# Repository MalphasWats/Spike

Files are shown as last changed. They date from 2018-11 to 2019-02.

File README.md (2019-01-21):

# Spike

Spike is a handheld gaming console based on ATMega Microcontrollers.

Spike

I've been playing around with this idea for a long while and the Spike is the current 'state-of-the-art' for me.

The main spike board has:

* 128x64px monochrome OLED display
* Piezo speaker
* 7 buttons (plus reset)
* 3.7v Lipo battery
* Micro-USB port for charging & data

Spike Exploded

The *shard* board provides the brains and connects via an edge connector on the back of the main board.

Currently I'm using an ATMega1284p running at 16MHz.

I've written a little [more detail on my blog](http://www.subdimension.co.uk/2019/01/16/spike-next-gen-portable-gaming.html).

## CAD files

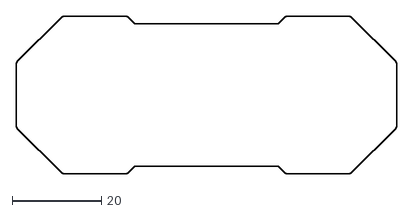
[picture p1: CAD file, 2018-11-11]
board_outline.dxf
85.3 x 35.3

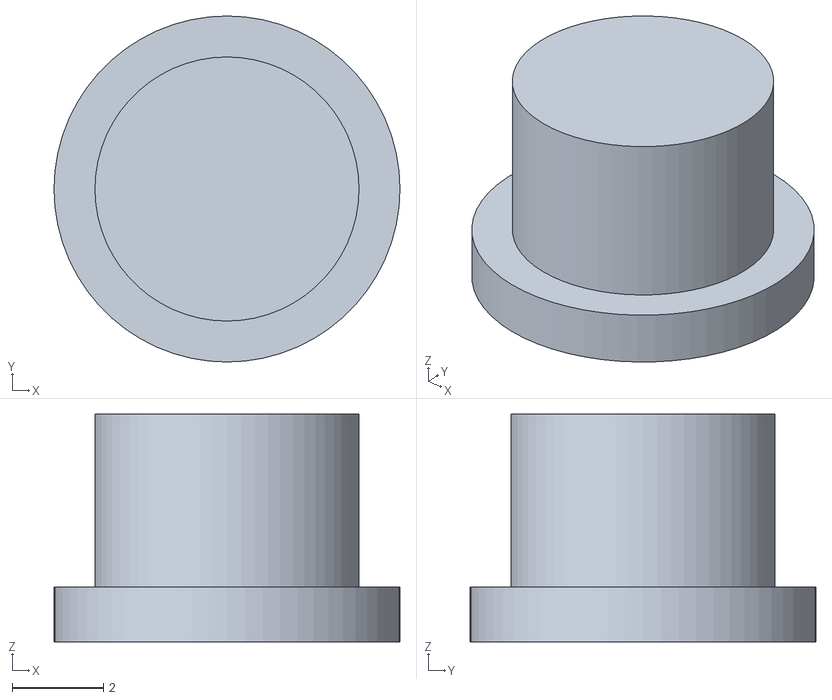
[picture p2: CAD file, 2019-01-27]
case/button-caps.stl
7.60 x 7.60 x 5.00

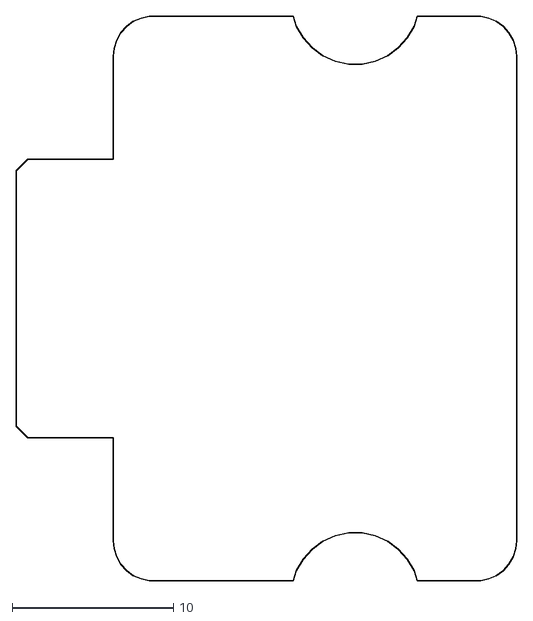
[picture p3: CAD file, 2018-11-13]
shard/outline.dxf
31.0 x 35.0

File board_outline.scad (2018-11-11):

module spike()
{
    minkowski()
    {
        union()
        {
            rotate([0, 0, 360/16]) circle(r=18, $fn=8);
            translate([50, 0, 0]) rotate([0, 0, 360/16]) circle(r=18, $fn=8);
            translate([25, 0]) square([32, 30], center=true);
        }
        circle(r=1, $fn=60);
    }
}

module shard()
{
    difference()
    {
        minkowski()
        {
            square([20, 30]);
            circle(r=2.5, $fn=30);
        }
        translate([12.5, -2.5-1]) circle(r=4, $fn=30);
        translate([12.5, 32.5+1]) circle(r=4, $fn=30);
    }
}

//color("red") translate([25, 0, 0.1]) square([28, 28], center=true);

spike();

//translate([40, -12, -2]) rotate([0, 0, 90]) color("blue") shard();

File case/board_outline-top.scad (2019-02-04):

module spike()
{
    minkowski()
    {
        union()
        {
            rotate([0, 0, 360/16]) circle(r=18, $fn=8);
            translate([50, 0, 0]) rotate([0, 0, 360/16]) circle(r=18, $fn=8);
            translate([25, 0]) square([32, 30], center=true);
        }
        circle(r=1, $fn=60);
    }
}

hole_size = 2 + 0.1;

difference()
{
    /*scale([1.02, 1.02])*/ translate([-25, 0]) spike();
    
    
    translate([-19, 15]) circle(d=hole_size, $fn=30);
    translate([19, 15]) circle(d=hole_size, $fn=30);
    
    translate([-31, -15]) circle(d=hole_size, $fn=30);
    translate([31, -15]) circle(d=hole_size, $fn=30);
    

    
        
    // Buttons
    
    translate([-25, 5]) rotate([0, 0, 45]) minkowski()
    {
        square([5, 5], center=true);
        circle(r=0.5, $fn=30);
    }
    
    translate([-25, -5]) rotate([0, 0, 45]) minkowski()
    {
        square([5, 5], center=true);
        circle(r=0.5, $fn=30);
    }
    
    translate([-30, 0]) rotate([0, 0, 45]) minkowski()
    {
        square([5, 5], center=true);
        circle(r=0.5, $fn=30);
    }
    translate([-20, 0]) rotate([0, 0, 45]) minkowski()
    {
        square([5, 5], center=true);
        circle(r=0.5, $fn=30);
    }
    
    // Case Mask
    /*translate([-25, 0]) rotate([0, 0, 45]) minkowski()
    {
        square([14, 14], center=true);
        circle(r=0.5, $fn=30);
    }*/
    
    
    translate([25, 5]) rotate([0, 0, 45]) minkowski()
    {
        square([5, 5], center=true);
        circle(r=0.5, $fn=30);
    }
    
    translate([25, -5]) rotate([0, 0, 45]) minkowski()
    {
        square([5, 5], center=true);
        circle(r=0.5, $fn=30);
    }
    
    translate([30, 0]) rotate([0, 0, 45]) minkowski()
    {
        square([5, 5], center=true);
        circle(r=0.5, $fn=30);
    }
    
    // Case Mask
    /*translate([25, 0]) rotate([0, 0, 45]) minkowski()
    {   
        difference()
        {
            square([14, 14], center=true);
            translate([-4, 4]) minkowski()
            {
                square([6, 6], center=true);
                circle(r=0.5, $fn=30);
            }
        }
        circle(r=0.5, $fn=30);
    }*/
    
    // usb
    translate([36, 11]) rotate([0, 0, -45]) minkowski()
    {
        square([6, 5], center=true);
        circle(r=0.5, $fn=30);
    }
    
}

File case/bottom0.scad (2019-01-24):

module spike()
{
    minkowski()
    {
        union()
        {
            rotate([0, 0, 360/16]) circle(r=18, $fn=8);
            translate([50, 0, 0]) rotate([0, 0, 360/16]) circle(r=18, $fn=8);
            translate([25, 0]) square([32, 30], center=true);
        }
        circle(r=1, $fn=60);
    }
}

hole_size = 2 + 0.1;

difference()
{
    scale([1.02, 1.02]) spike();
    
    
    translate([-15, 6.25]) circle(d=hole_size, $fn=30);
    translate([65.25, 6.25]) circle(d=hole_size, $fn=30);
    
    translate([-7.75, -13.25]) circle(d=hole_size, $fn=30);
    translate([57.75, -13.25]) circle(d=hole_size, $fn=30);
    
    
    // Battery Connector
    /*translate([52.00, 7]) hull()
    {
        circle(d=8, $fn=30);
        translate([-10.00, 0]) circle(d=8, $fn=30);
    }*/
    
    translate([50.00, 1]) minkowski()
    {
        square([15, 20], center=true);
        circle(d=1, $fn=30);
    }
    
    // Speaker
    translate([-7, 0]) circle(r=7, $fn=30);
    translate([-7, -7]) square([4, 4], center=true);
    
    // Shard socket
    translate([16, -17]) minkowski()
    {
        square([18, 10]);
        circle(r=0.8, $fn=30);
    }
    
    translate([16, 1]) minkowski()
    {
        square([18, 15]);
        circle(r=0.8, $fn=30);
    }
    
    /*translate([60, 12]) rotate([0, 0, 45]) minkowski()
    {
        square([4, 6], center=true);
        circle(r=0.5, $fn=30);
    }*/
    
    /*translate([40, -6]) rotate([0, 0, 90]) minkowski()
    {
        square([20, 30]);
        circle(r=2.5, $fn=30);
    }*/
}

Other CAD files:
case/base.scad
case/bottom1.scad
case/bottom2.scad
case/button-caps.scad
case/top0.scad
shard/outline.scad
shard_1284/outline.scad
shard_t84/outline.scad

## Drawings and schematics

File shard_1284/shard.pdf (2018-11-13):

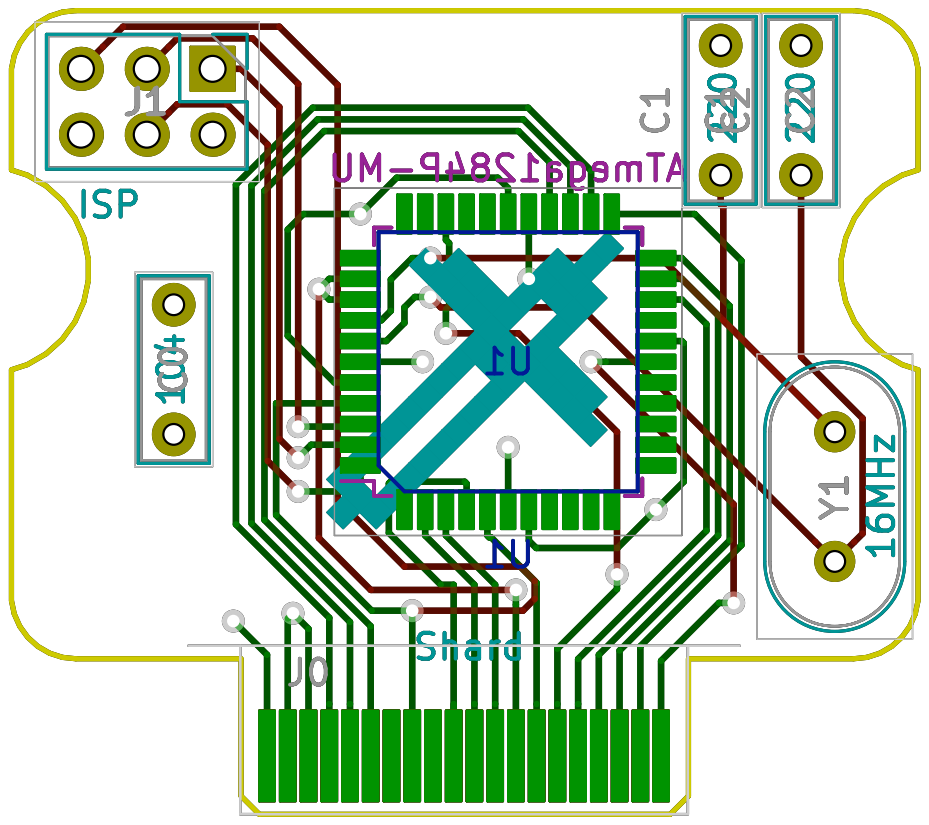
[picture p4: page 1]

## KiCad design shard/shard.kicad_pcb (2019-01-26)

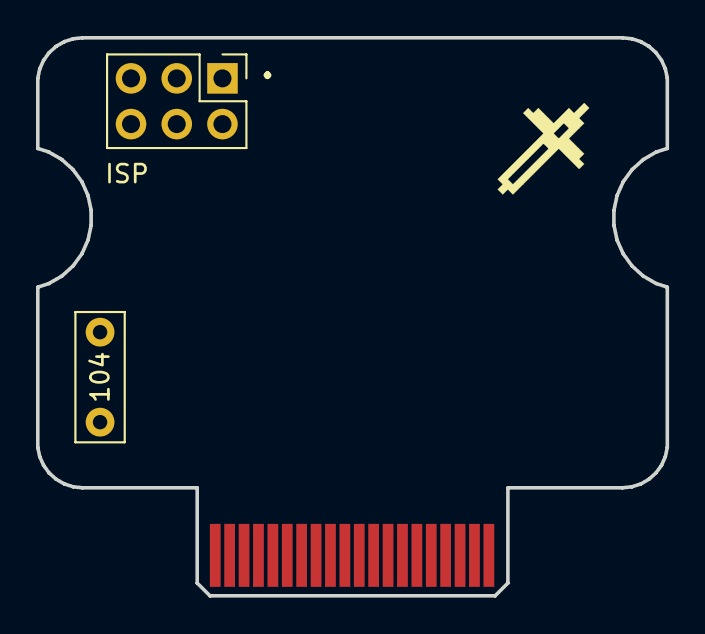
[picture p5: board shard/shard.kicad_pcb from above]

Board: 2 copper layers, 35.0 x 31.0 mm, 4 parts (0 on the bottom side), 3 nets, no tracks yet.

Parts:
C0: 104; C_Rect_L7.0mm_W2.5mm_P5.00mm
J0: Shard; Samtec_MEC8-120-02-L-D-RA1_Edge
J1: ISP; PinHeader_2x03_P2.54mm_Vertical
SPIKE: SPIKE

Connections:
+3V3: C0.1, J0.2, J1.2
GND: C0.2, J0.40, J1.6
RESET: J0.16, J1.5

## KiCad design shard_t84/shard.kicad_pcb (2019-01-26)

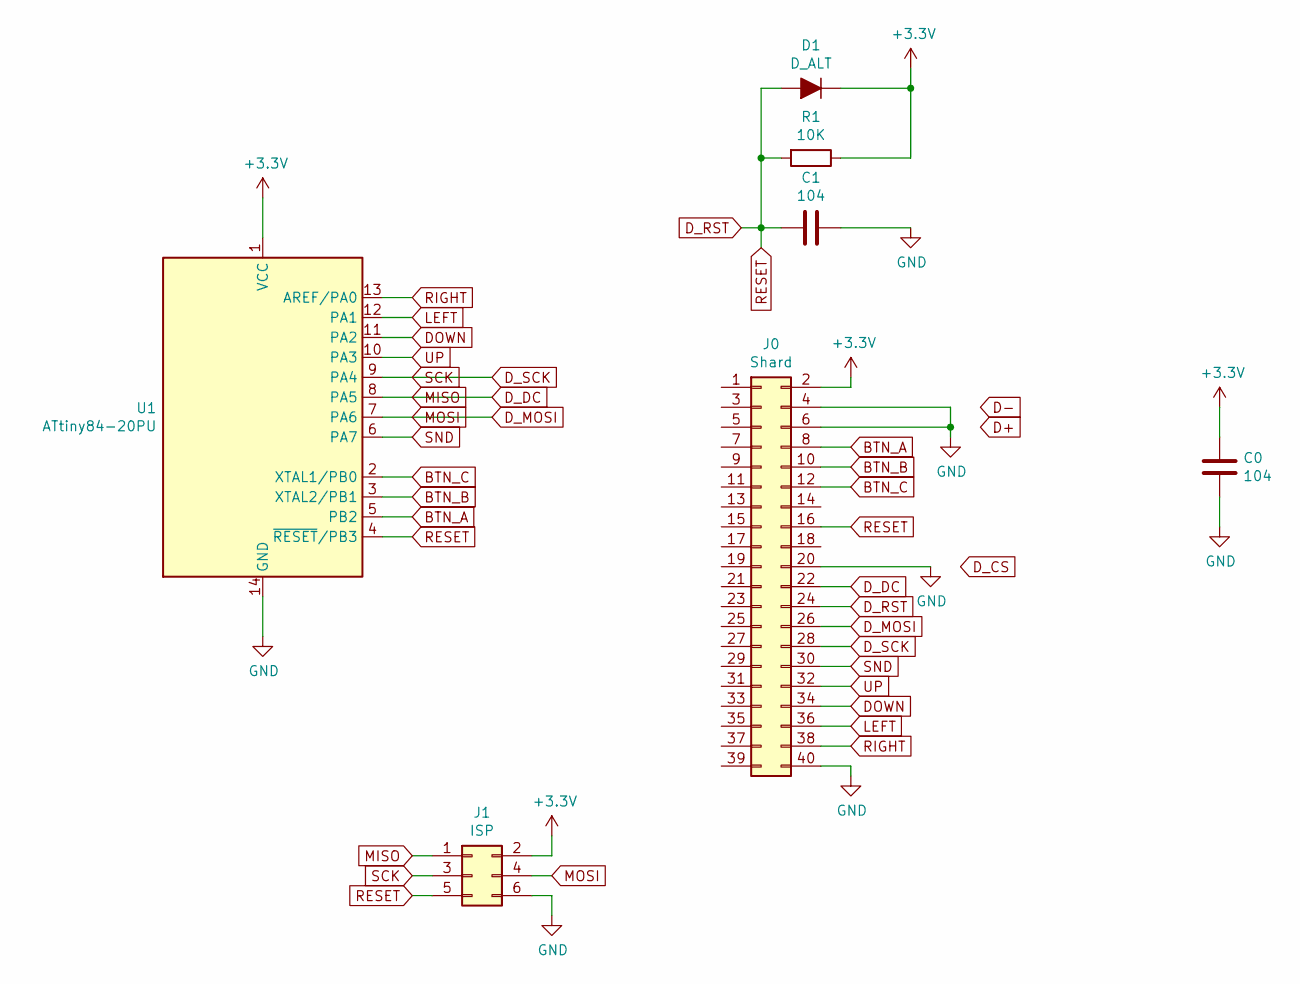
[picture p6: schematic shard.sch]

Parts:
C0, C1: 104; C_Rect_L7.0mm_W2.5mm_P5.00mm
D1: D_ALT; D_A-405_P7.62mm_Horizontal
J0: Shard; Samtec_MEC8-120-02-L-D-RA1_Edge
J1: ISP; PinHeader_2x03_P2.54mm_Vertical
R1: 10K; R_Axial_DIN0207_L6.3mm_D2.5mm_P7.62mm_Horizontal
U1: ATtiny84-20PU; DIP-14_W7.62mm

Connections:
+3V3: C0.1, D1.1 (K), J0.2, J1.2, R1.1, U1.1 (VCC)
BTN_A: J0.8, U1.5 (PB2)
BTN_B: J0.10, U1.3 (XTAL2/PB1)
BTN_C: J0.12, U1.2 (XTAL1/PB0)
DOWN: J0.34, U1.11 (PA2)
D_DC: J0.22, J1.1, U1.8 (PA5)
D_MOSI: J0.26, J1.4, U1.7 (PA6)
D_RST: C1.2, D1.2 (A), J0.16, J0.24, J1.5, R1.2, U1.4 (~RESET~/PB3)
D_SCK: J0.28, J1.3, U1.9 (PA4)
GND: C0.2, C1.1, J0.4, J0.6, J0.20, J0.40, J1.6, U1.14 (GND)
LEFT: J0.36, U1.12 (PA1)
RIGHT: J0.38, U1.13 (AREF/PA0)
SND: J0.30, U1.6 (PA7)
UP: J0.32, U1.10 (PA3)

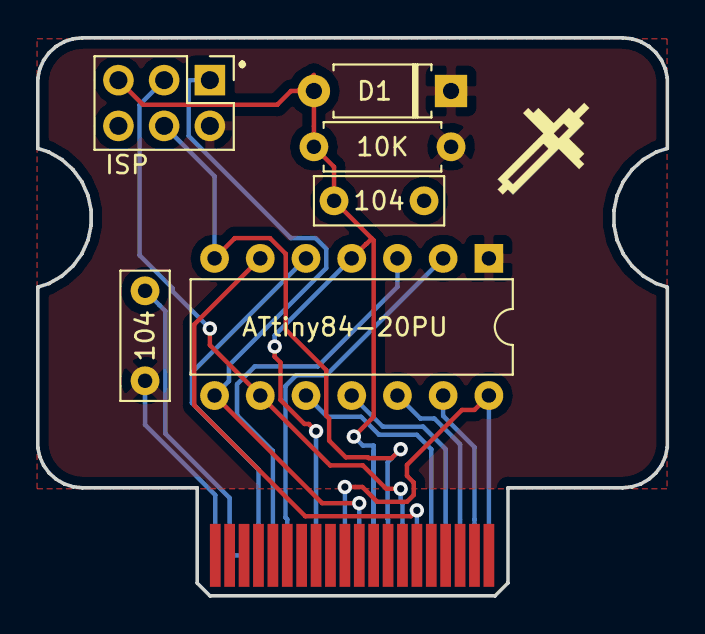
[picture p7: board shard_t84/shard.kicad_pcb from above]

Board: 2 copper layers, 35.0 x 31.0 mm, 8 parts (0 on the bottom side), 14 nets.

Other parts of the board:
SPIKE: SPIKE

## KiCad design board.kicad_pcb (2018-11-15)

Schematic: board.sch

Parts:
C1: 104; C_Rect_L7.0mm_W2.5mm_P5.00mm
C2, C3: 105; C_Rect_L7.0mm_W2.5mm_P5.00mm
C5, C6: 475; C_Rect_L7.0mm_W2.5mm_P5.00mm
D1: CHG; LED_D3.0mm
J0: Battery Pads; LiPo_Pads
J1: Shard; Samtec_MEC8-120-02-L-D-RA1_Socket
J2: USB-Micro; USB_Micro-B_Molex-105017-0001
LS1: Speaker; Generic_Speaker
R0: 1K; R_Axial_DIN0207_L6.3mm_D2.5mm_P7.62mm_Horizontal
R1: LED; R_Axial_DIN0207_L6.3mm_D2.5mm_P7.62mm_Horizontal
R2: 2K; R_Axial_DIN0207_L6.3mm_D2.5mm_P7.62mm_Horizontal
SW0: RESET; SW_PUSH_6mm
SW1: UP; SW_PUSH_6mm
SW2: DOWN; SW_PUSH_6mm
SW3: LEFT; SW_PUSH_6mm
SW4: RIGHT; SW_PUSH_6mm
SW5: BTN_A; SW_PUSH_6mm
SW6: BTN_B; SW_PUSH_6mm
SW7: BTN_C; SW_PUSH_6mm
SW8: POWER; SW_DIP_SPSTx01_Slide_9.78x4.72mm_W7.62mm_P2.54mm
U1: OLED; 128x64-OLED
U2: CHG CTRL; SOT-23-5
U3: Reg; SOT-23

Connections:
+3V3: C1.1, C3.1, J1.2, R0.1, U1.2, U3.2
+BATT: C6.1, J0.1, SW8.2, U2.3
BTN_A: J1.8, SW5.2
BTN_B: J1.10, SW6.2
BTN_C: J1.12, SW7.2
CHARGE: C5.1, D1.2, J2.1, U2.4
D+: J1.6, J2.3
D-: J1.4, J2.2
DOWN: J1.34, SW2.2
D_CS: J1.20, U1.7
D_DC: J1.22, U1.6
D_MOSI: J1.26, U1.4
D_RST: J1.24, U1.5
D_SCK: J1.28, U1.3
GND: C1.2, C2.2, C3.2, C5.2, C6.2, J0.2, J1.40, J2.4, J2.5, J2.6, LS1.1, R2.2, SW0.1, SW1.1, SW2.1, SW3.1, SW4.1, SW5.1, SW6.1, SW7.1, U1.1, U2.2, U3.1
LEFT: J1.36, SW3.2
unnamed: C2.1, SW8.1, U3.3
unnamed: D1.1, R1.2
unnamed: R1.1, U2.1
unnamed: R2.1, U2.5
RESET: J1.16, R0.2, SW0.2
RIGHT: J1.38, SW4.2
SND: J1.30, LS1.2
UP: J1.32, SW1.2

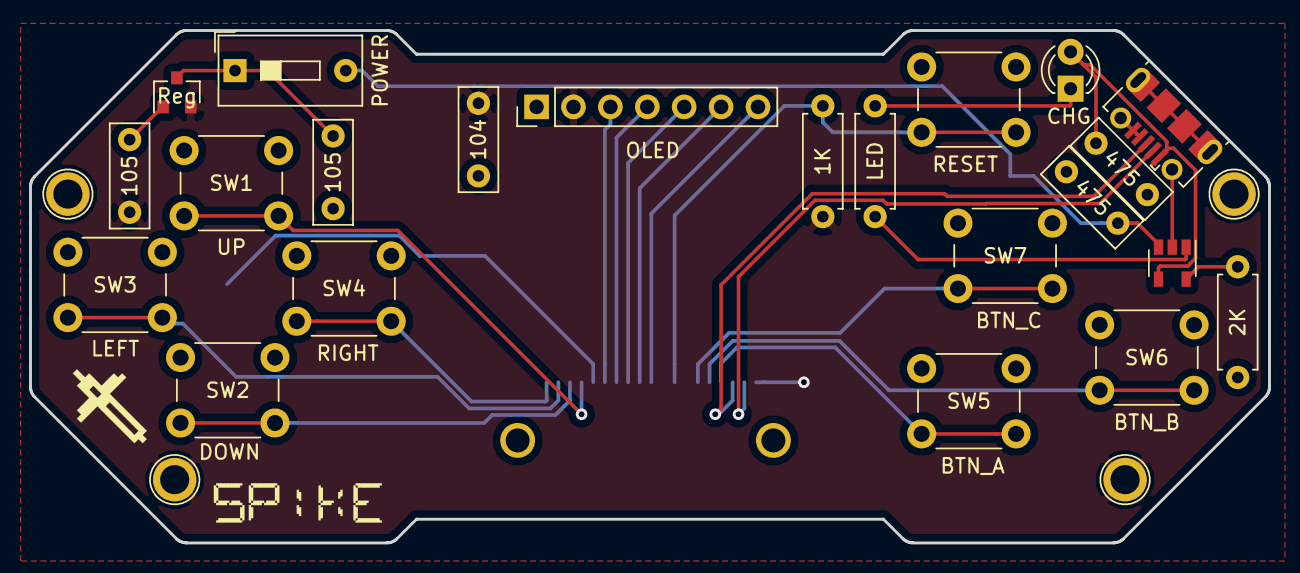
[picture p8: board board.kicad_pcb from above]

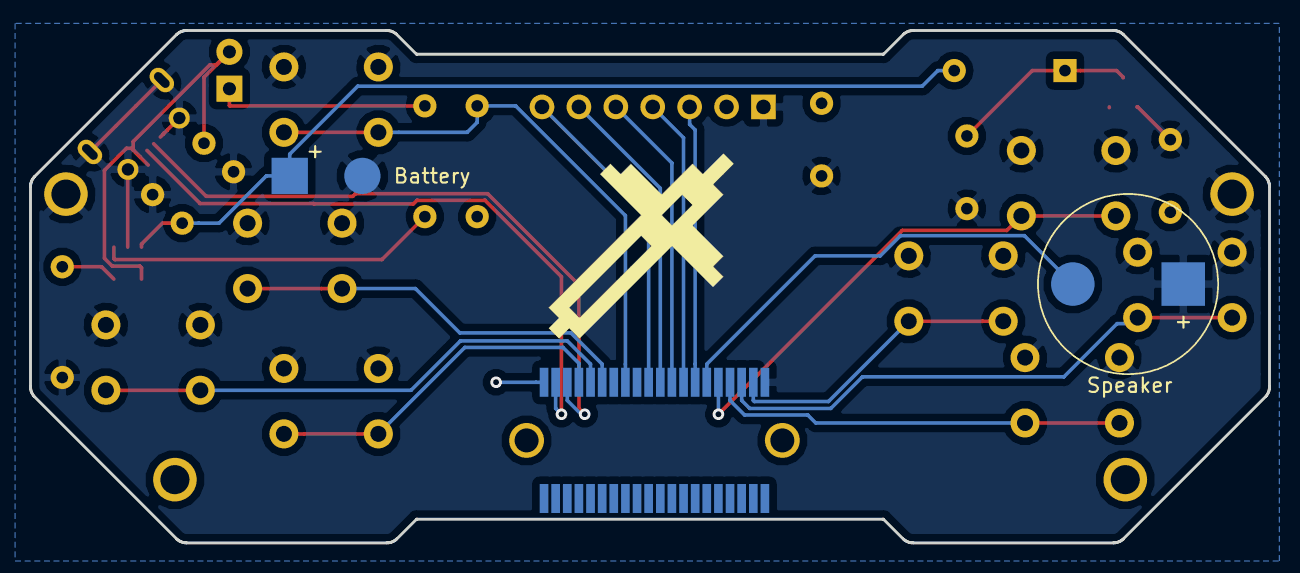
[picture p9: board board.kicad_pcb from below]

Board: 2 copper layers, 85.3 x 35.3 mm, 28 parts (4 on the bottom side), 24 nets.

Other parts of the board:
LOGO: LOGO
SPIKE: SPIKE
SPIKE#2: SPIKE

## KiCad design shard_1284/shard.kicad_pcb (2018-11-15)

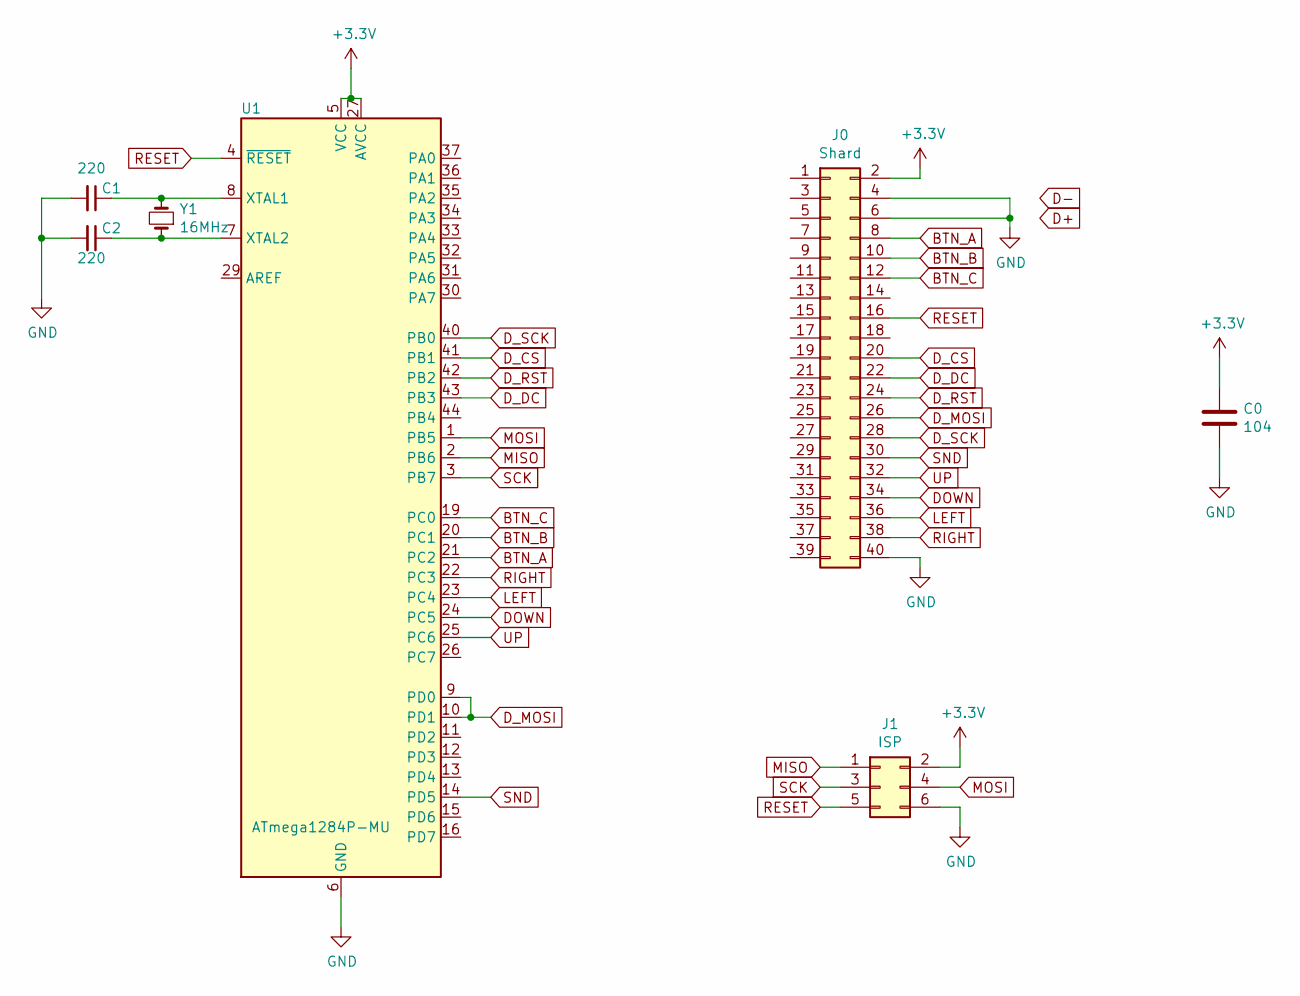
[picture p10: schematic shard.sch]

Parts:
C0: 104; C_Rect_L7.0mm_W2.5mm_P5.00mm
C1, C2: 220; C_Rect_L7.0mm_W2.5mm_P5.00mm
J0: Shard; Samtec_MEC8-120-02-L-D-RA1_Edge
J1: ISP; PinHeader_2x03_P2.54mm_Vertical
U1: ATmega1284P-MU; TQFP-44_10x10mm_P0.8mm
Y1: 16MHz; Resonator-2Pin_W10.0mm_H5.0mm

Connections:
+3V3: C0.1, J0.2, J1.2, U1.5 (VCC), U1.17 (VCC), U1.27 (AVCC), U1.38 (VCC)
BTN_A: J0.8, U1.21 (PC2)
BTN_B: J0.10, U1.20 (PC1)
BTN_C: J0.12, U1.19 (PC0)
DOWN: J0.34, U1.24 (PC5)
D_CS: J0.20, U1.41 (PB1)
D_DC: J0.22, U1.43 (PB3)
D_MOSI: J0.26, U1.9 (PD0), U1.10 (PD1)
D_RST: J0.24, U1.42 (PB2)
D_SCK: J0.28, U1.40 (PB0)
GND: C0.2, C1.2, C2.2, J0.4, J0.6, J0.40, J1.6, U1.6 (GND), U1.18 (GND), U1.28 (GND), U1.39 (GND)
LEFT: J0.36, U1.23 (PC4)
MISO: J1.1, U1.2 (PB6)
MOSI: J1.4, U1.1 (PB5)
unnamed: C1.1, U1.8 (XTAL1), Y1.2
unnamed: C2.1, U1.7 (XTAL2), Y1.1
RESET: J0.16, J1.5, U1.4 (~RESET)
RIGHT: J0.38, U1.22 (PC3)
SCK: J1.3, U1.3 (PB7)
SND: J0.30, U1.14 (PD5)
UP: J0.32, U1.25 (PC6)

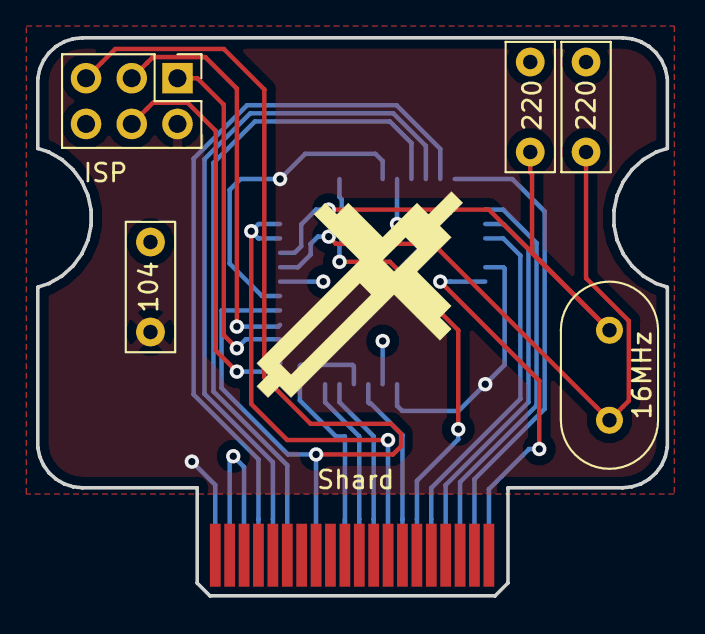
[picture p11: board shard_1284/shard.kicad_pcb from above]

Board: 2 copper layers, 35.0 x 31.0 mm, 8 parts (1 on the bottom side), 21 nets.

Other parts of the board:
SPIKE: SPIKE

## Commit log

2018-09-27 initial import
    [board.kicad_pcb, board.sch, board_outline.dxf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]
2018-09-28 Updated Layout
    [board.kicad_pcb, board.sch, board_outline.dxf]
2018-10-03 Added tracks
    [board.kicad_pcb, board.sch]
2018-10-09 added crystal
    [board.kicad_pcb, board.sch]
2018-10-09 Revert "added crystal"
    This reverts commit 60f505991b0e3ccfce5c63fb45a6584053ac2d9c.
    [board.kicad_pcb, board.sch]
2018-10-09 Changed labels
    [board.sch]
2018-10-09 Revert "Revert "added crystal""
    This reverts commit 7f3a5123c106fe465dc47a4e88f841c035e49e56.
    [board.kicad_pcb, board.sch]
2018-10-09 sorted crystal
    I think. Got into a proper pickle there.
    [board.kicad_pcb, board.sch]
2018-10-16 crystal I think
    [board.kicad_pcb]
2018-10-28 reworked to be MCU agnostic
    [board.kicad_pcb, board.sch, board_outline.scad]
2018-10-28 basic shard template
    [outline.dxf, outline.scad, shard.kicad_pcb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]
2018-10-28 Shard_1284 initial implementation
    [outline.dxf, outline.scad, shard.kicad_pcb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]
2018-10-28 t84 shard
    [outline.dxf, outline.scad, shard.kicad_pcb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]
2018-10-29 added mounting holes
    [board.kicad_pcb, shard.kicad_pcb]
2018-10-30 shard template fixed
    [shard.kicad_pcb]
2018-10-30 added capacitor value
    [shard.kicad_pcb, shard.sch]
2018-10-30 disconnected D- & D+ to fix GND net
    [shard.kicad_pcb, shard.sch]
2018-10-30 reworked board for correct connector orientation
    [shard.kicad_pcb]
2018-11-11 board revised for mono oled
    [board.kicad_pcb, board.sch, board_outline.dxf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]
2018-11-11 t84 shard updated for new layout
    [shard.kicad_pcb, shard.sch]
2018-11-11 swapped buttons to pull to GND
    [board.kicad_pcb, board.sch]
2018-11-12 flip connector
    [shard.kicad_pcb, shard.sch]
2018-11-12 Edge Connector for Shards
    [board.kicad_pcb, board.sch]
2018-11-12 updated for edge connector
    [shard.kicad_pcb, shard.sch]
2018-11-13 Board updated to edge connector
    [board.kicad_pcb, board.sch]
2018-11-13 Template updated to edge connector
    [outline.dxf, outline.scad, shard.kicad_pcb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]
2018-11-13 outline updated
    [outline.dxf, outline.scad]
2018-11-13 1284 shard updated to edge connector
    [outline.dxf, outline.scad, shard.kicad_pcb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]
2018-11-14 changed 3.3v track to via instead of mounting point
    [board.kicad_pcb]
2018-11-15 label tweaks
    [board.kicad_pcb]
2018-11-15 flipped logo to match shard
    [board.kicad_pcb]
2018-11-15 tweaked labels
    [_saved_shard.sch, board.kicad_pcb, shard.kicad_pcb]
2019-01-24 simple case idea
    [base.scad, bottom0.scad, bottom1.scad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]
2019-01-24 this one didn't work out
    [outline.dxf, outline.scad, shard.kicad_pcb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]
2019-01-26 Revert "this one didn't work out"
    This reverts commit 10e7dd97264609a345ca62be13df3977391ce221.
    [outline.dxf, outline.scad, shard.kicad_pcb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]
2019-01-26 fixed issues with shard
    [shard.kicad_pcb, shard.sch]
2019-01-27 button cap
    [button-caps.scad, button-caps.stl]
2019-01-30 top case
    [top0.scad]
2019-01-30 little bit extra
    [top0.scad]
2019-01-30 tweak size
    [top0.scad]
2019-02-04 ignoring some things
    [board_outline-top.scad]
